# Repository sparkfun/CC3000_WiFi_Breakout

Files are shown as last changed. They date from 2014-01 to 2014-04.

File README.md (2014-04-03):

CC3000_WiFi_Breakout
====================

[TI CC3000 WiFi Breakout Board  
*CC3000 WiFi Breakout Board (WRL-12072)*](https://www.sparkfun.com/products/12072)

WiFi breakout board for the [TI CC3000 module](http://www.ti.com/product/cc3000). The datasheet can be found [here](http://www.ti.com/lit/ds/symlink/cc3000.pdf).

Arduino library and examples can be found in the [SFE_CC3000_Library](https://github.com/sparkfun/SFE_CC3000_Library).

This part was created in Eagle v6.5.0. Example sketches were created in Arduino v1.0.5.

Repository Contents
-------------------

* **/Fritzing** - [Fritzing](http://fritzing.org/) part files
* **/Hardware** - All Eagle design files (.brd, .sch, .STL)
* **/Production** - Test bed files and production panel files

Version History
---------------
* **v1.0** Initial release

License Information
-------------------
The hardware is released under [Creative Commons Share-alike 3.0](http://creativecommons.org/licenses/by-sa/3.0/).  
All other code is open source so please feel free to do anything you want with it; you buy me a beer if you use this and we meet someday ([Beerware license](http://en.wikipedia.org/wiki/Beerware)).

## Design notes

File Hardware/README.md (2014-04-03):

# What Are these Files?

The .sch and .brd files hare are Eagle CAD schematic and PCB design files.

These files were created with Eagle 6.5.0, you'll need Eagle 6.5 or later to open them up. There is a free, lite, version of Eagle available from [cadsoftusa.com](cadsoftusa.com).

# License

This product is open source! These Eagle files are released under the Creative Commons Share-Alike Attribution license ([CC BY-SA 3.0](http://creativecommons.org/licenses/by-sa/3.0/us/)).

Please use, reuse, and modify these files as you see fit. Please maintain attribution and release anything derivative under the same license.

- Your friends at SparkFun.

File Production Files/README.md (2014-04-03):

These are the production files SparkFun uses for printing PCBs, as well as the Eagle files for our test beds.

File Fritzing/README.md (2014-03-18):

* Fritzing diagram showing the CC3000 WiFi Breakout Board connected to an [Arduino Uno](https://www.sparkfun.com/products/11021)
* The subfolder contains the source files for Fritzing diagrams for the CC3000 Breakout Board.

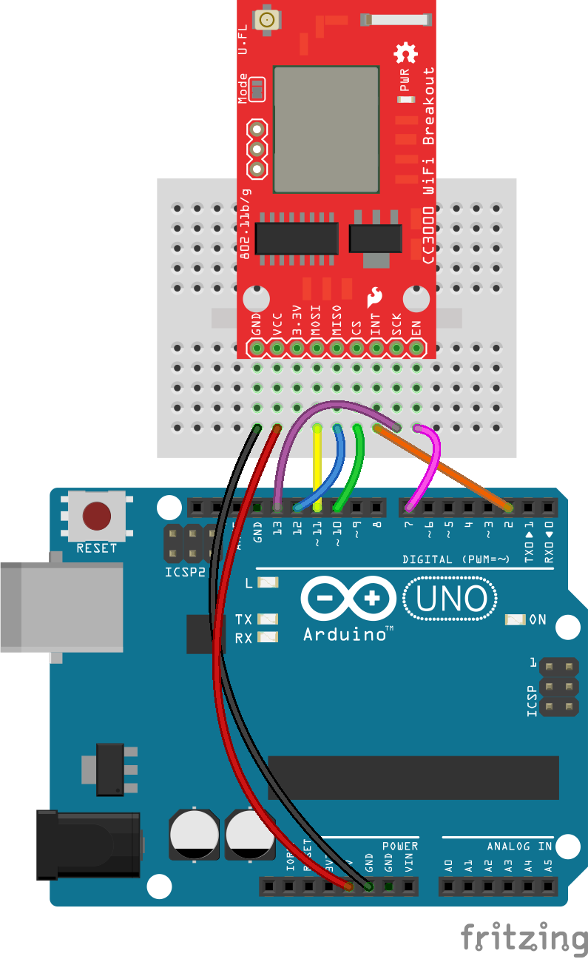
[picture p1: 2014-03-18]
Fritzing/CC3000_Breakout_Arduino_Example.png

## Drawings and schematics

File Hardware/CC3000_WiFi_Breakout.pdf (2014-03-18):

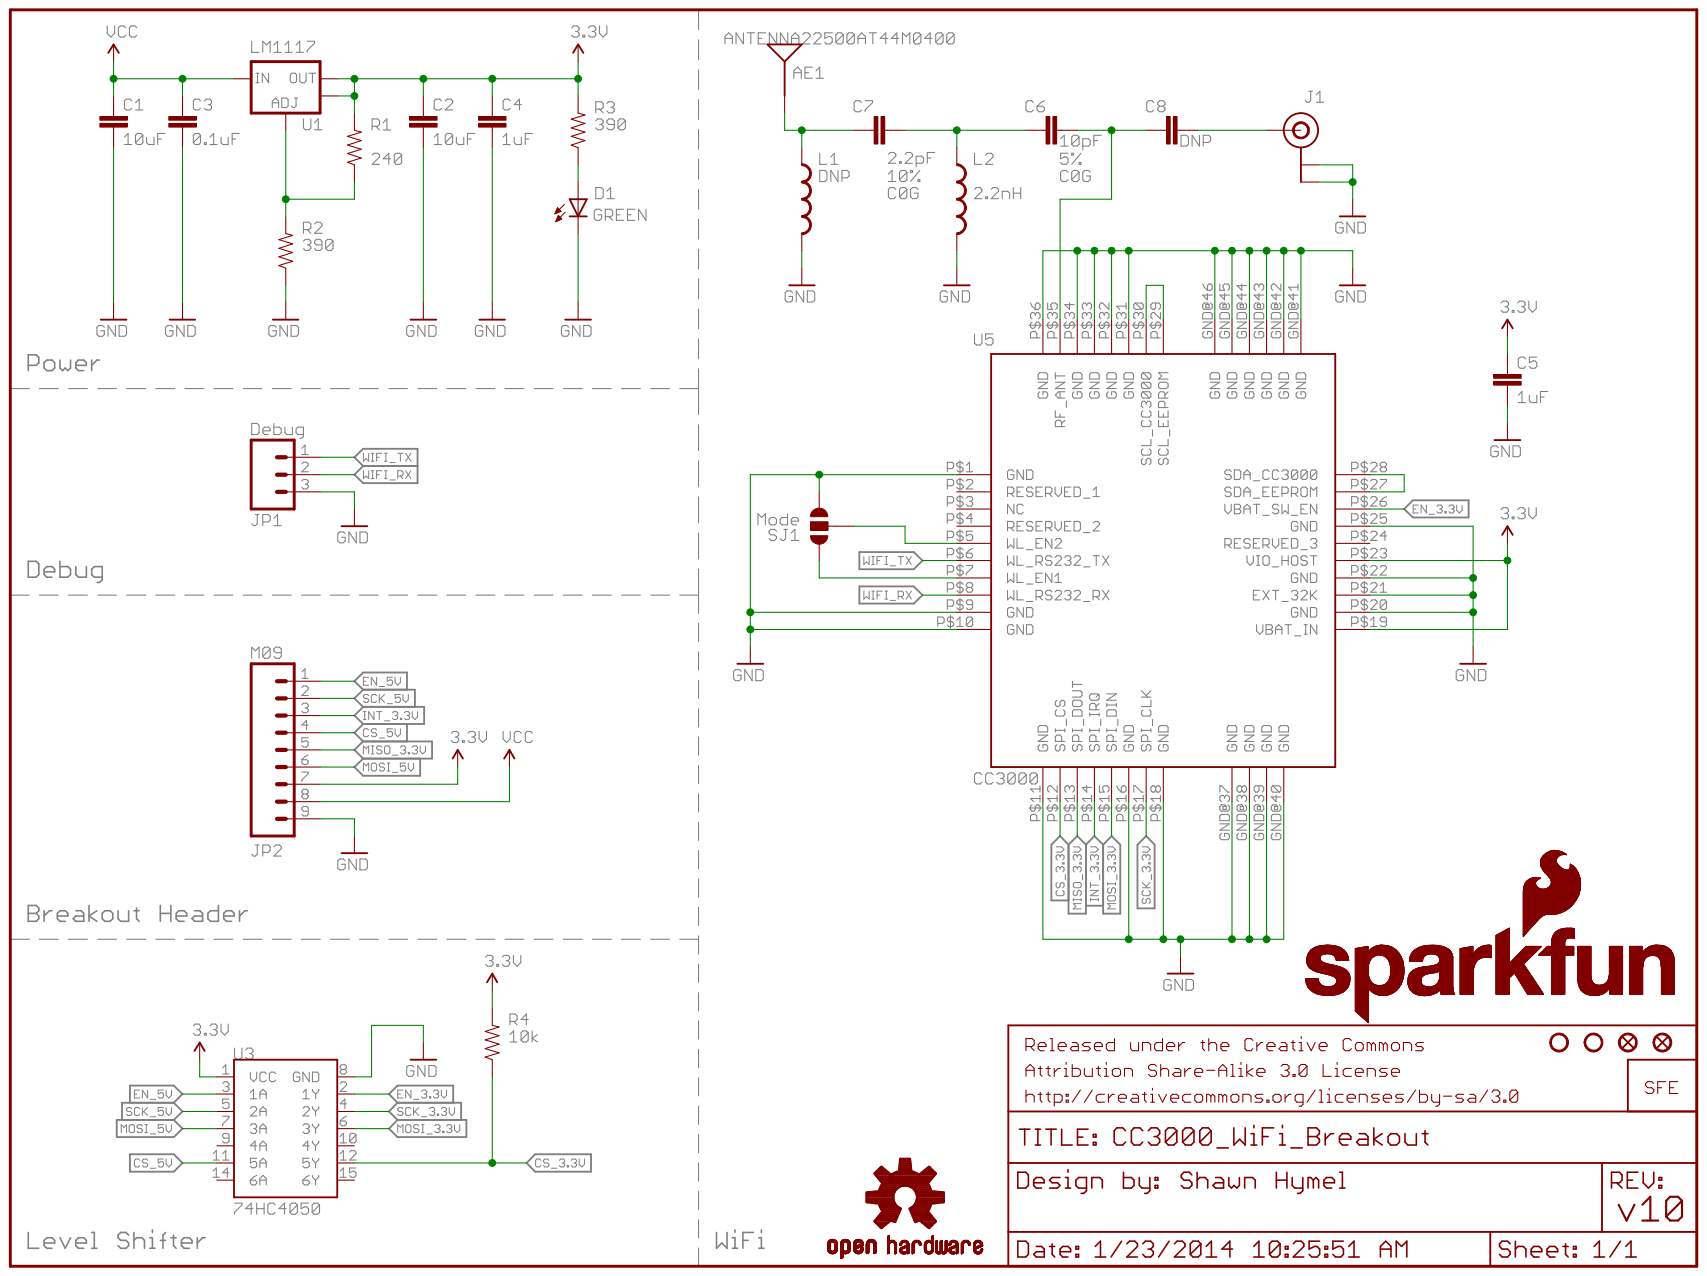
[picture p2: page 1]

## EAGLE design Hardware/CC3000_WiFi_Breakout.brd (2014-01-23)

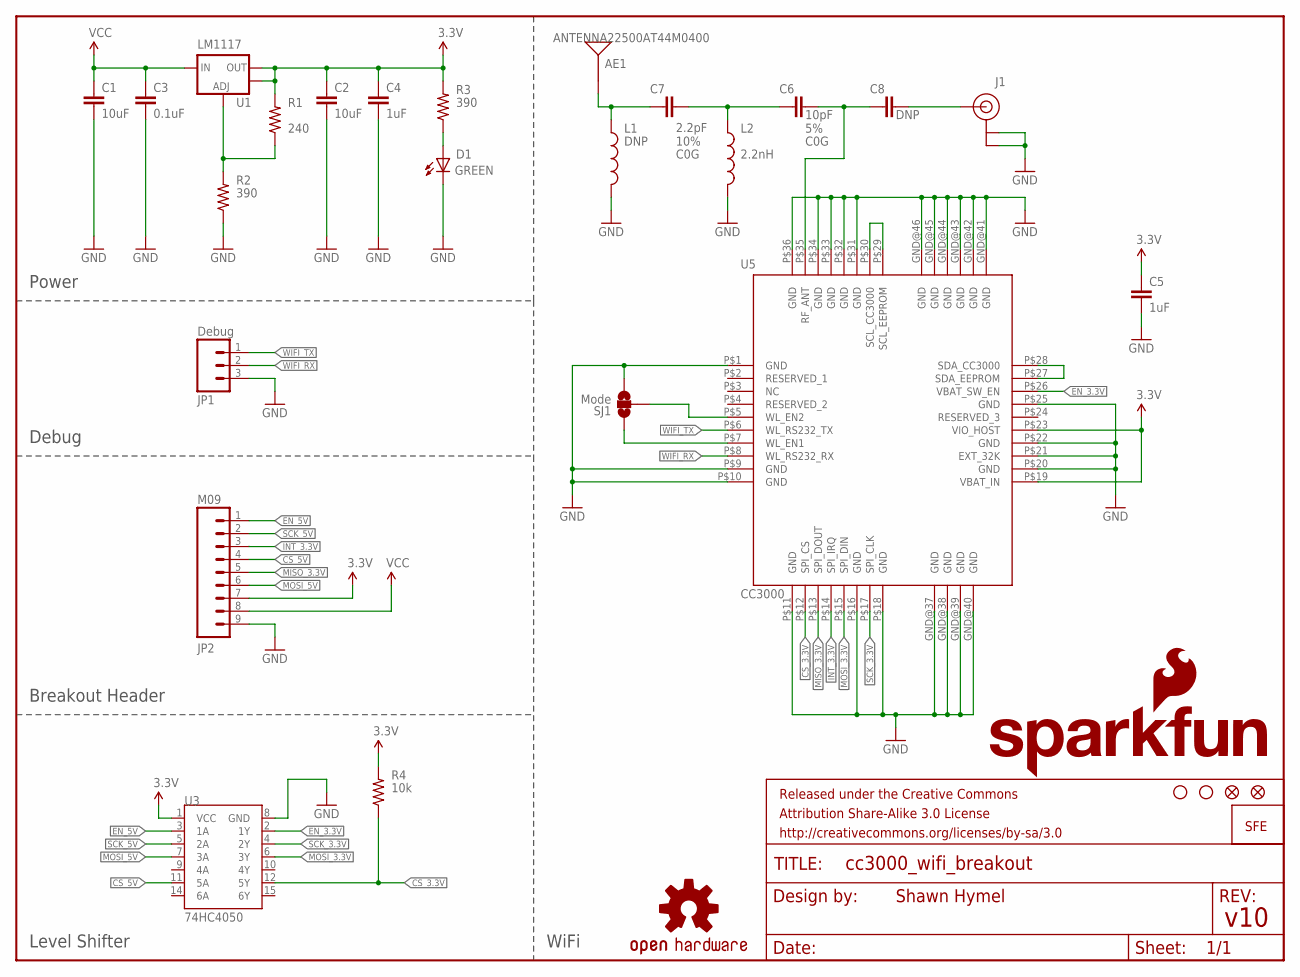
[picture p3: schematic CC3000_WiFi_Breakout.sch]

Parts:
AE1: ANTENNA22500AT44M0400; ANTENNA-CHIP_2500AT44M0400
C1, C2: 10uF; 0805
C3: 0.1uF; 0603-CAP
C4, C5: 1uF; 0805
C6: 10pF; 0603-CAP
C7: 2.2pF; 0603-CAP
C8: DNP; 0603-CAP
D1: GREEN; LED-0603
FID1, FID2: FIDUCIAL1X2; FIDUCIAL-1X2
FRAME1: FRAME-LETTER; CREATIVE_COMMONS
J1: U.FL
JP1: Debug; 1X03
JP2: M09; 1X09
L1: DNP; 0603
L2: 2.2nH; 0603
LOGO1: OSHW-LOGOS; OSHW-LOGO-S
LOGO3: LOGO-SFESK; SFE-LOGO-FLAME
LOGO4: SFE_LOGO_NAME_FLAME.1_INCH; SFE_LOGO_NAME_FLAME_.1
R1: 240; 0603-RES
R2, R3: 390; 0603-RES
R4: 10k; 0603-RES
SJ1: Mode; SJ_3_PASTE1&2
STANDOFF1, STANDOFF2: STAND-OFF
U1: LM1117; SOT223
U3: 74HC4050; SO016
U5: CC3000; QFN-46_CC3000

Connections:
3.3V: C2.1, C4.1, C5.1, JP2.7, R1.2, R3.2, R4.2, U1.2 (OUT), U1.4 (OUT), U3.1 (VCC), U5.P$19 (VBAT_IN), U5.P$23 (VIO_HOST)
CS_3.3V: R4.1, U3.12 (5Y), U5.P$12 (SPI_CS)
CS_5V: JP2.4, U3.11 (5A)
EN_3.3V: U3.2 (1Y), U5.P$26 (VBAT_SW_EN)
EN_5V: JP2.1, U3.3 (1A)
GND: C1.2, C2.2, C3.2, C4.2, C5.2, D1.C, J1.P$1 (GND), J1.P$2 (GND), JP1.3, JP2.9, L1.2, L2.2, R2.1, SJ1.3, U3.8 (GND), U5.GND@37 (GND), U5.GND@38 (GND), U5.GND@39 (GND), U5.GND@40 (GND), U5.GND@41 (GND), U5.GND@42 (GND), U5.GND@43 (GND), U5.GND@44 (GND), U5.GND@45 (GND), U5.GND@46 (GND), U5.P$1 (GND), U5.P$9 (GND), U5.P$10 (GND), U5.P$11 (GND), U5.P$16 (GND), U5.P$18 (GND), U5.P$20 (GND), U5.P$21 (EXT_32K), U5.P$22 (GND), U5.P$25 (GND), U5.P$31 (GND), U5.P$32 (GND), U5.P$33 (GND), U5.P$34 (GND), U5.P$36 (GND)
INT_3.3V: JP2.3, U5.P$14 (SPI_IRQ)
MISO_3.3V: JP2.5, U5.P$13 (SPI_DOUT)
MOSI_3.3V: U3.6 (3Y), U5.P$15 (SPI_DIN)
MOSI_5V: JP2.6, U3.7 (3A)
unnamed: R1.1, R2.2, U1.1 (ADJ)
unnamed: SJ1.2, U5.P$5 (WL_EN2)
unnamed: SJ1.1, U5.P$7 (WL_EN1)
unnamed: C6.1, C7.2, L2.1
unnamed: U5.P$27 (SDA_EEPROM), U5.P$28 (SDA_CC3000)
unnamed: U5.P$29 (SCL_EEPROM), U5.P$30 (SCL_CC3000)
unnamed: C6.2, C8.1, U5.P$35 (RF_ANT)
unnamed: C8.2, J1.P$3 (SIGNAL)
unnamed: AE1.FEED, C7.1, L1.1
unnamed: D1.A, R3.1
SCK_3.3V: U3.4 (2Y), U5.P$17 (SPI_CLK)
SCK_5V: JP2.2, U3.5 (2A)
VCC: C1.1, C3.1, JP2.8, U1.3 (IN)
WIFI_RX: JP1.2, U5.P$8 (WL_RS232_RX)
WIFI_TX: JP1.1, U5.P$6 (WL_RS232_TX)

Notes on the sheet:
Shawn Hymel
v10
Power
Debug
Breakout Header
Level Shifter
WiFi

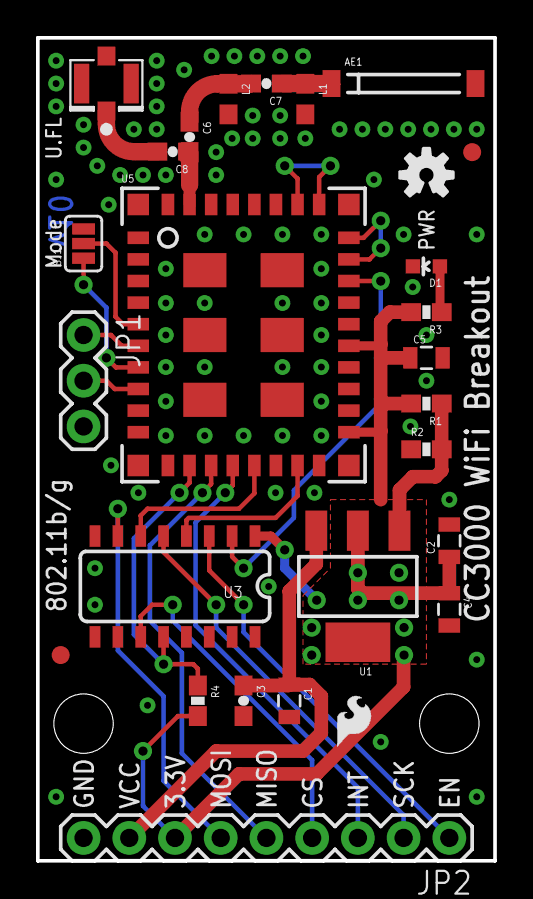
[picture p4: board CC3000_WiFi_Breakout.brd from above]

Board: 2 copper layers, 25.4 x 45.7 mm, 31 parts (1 on the bottom side), 25 nets.

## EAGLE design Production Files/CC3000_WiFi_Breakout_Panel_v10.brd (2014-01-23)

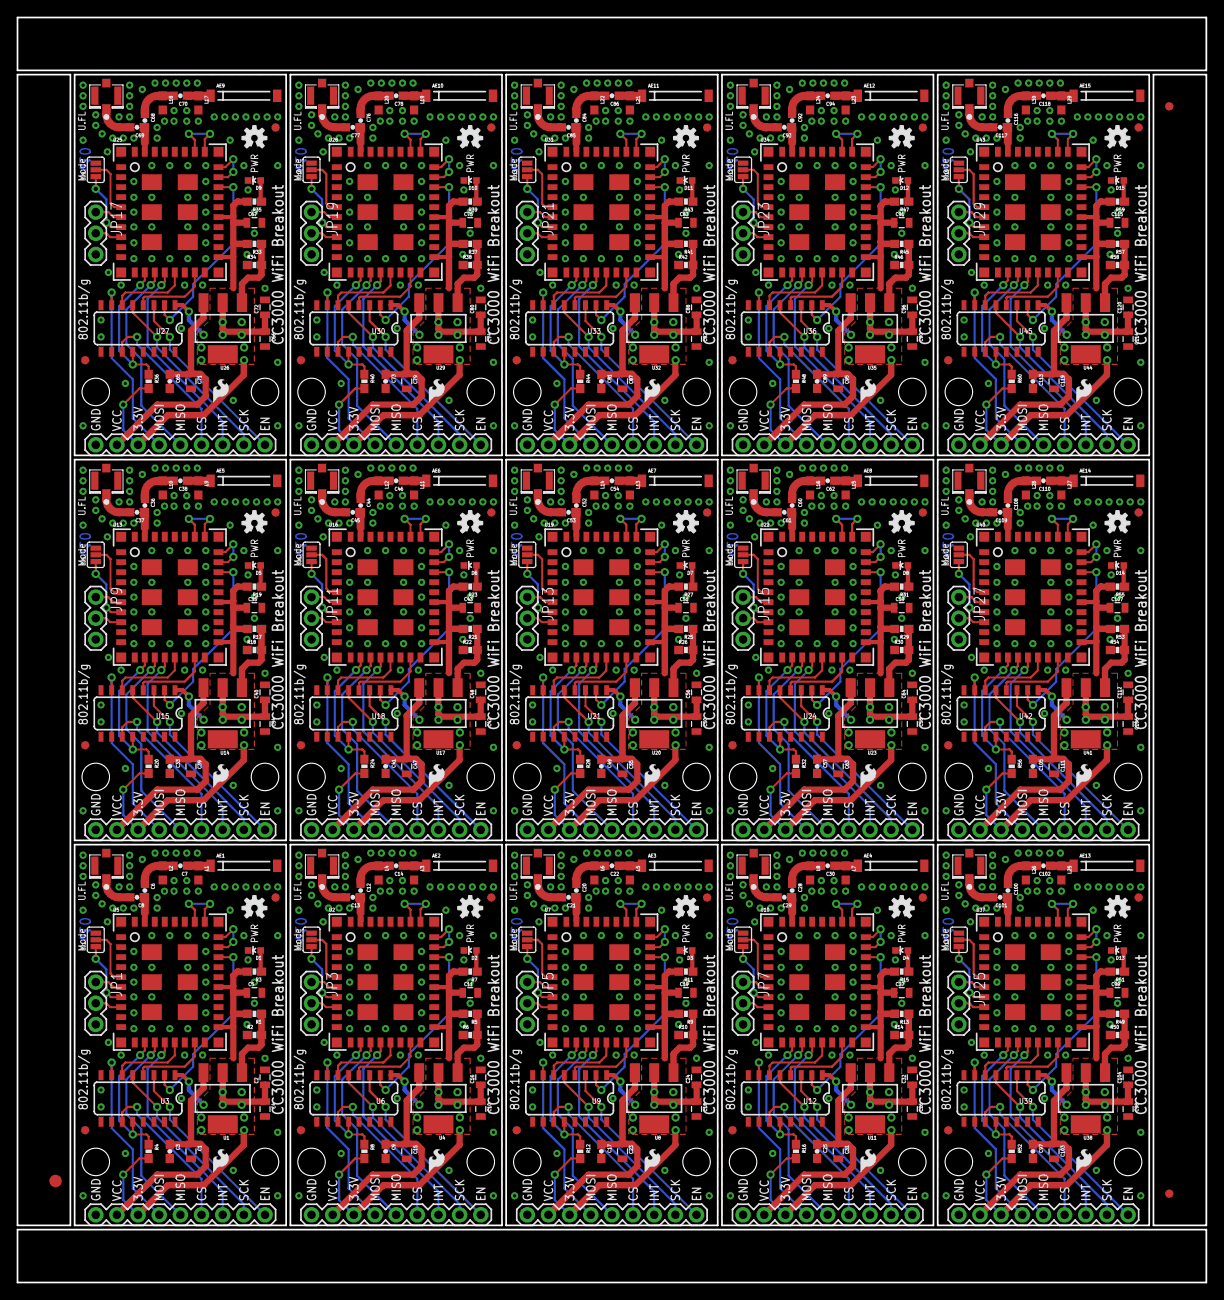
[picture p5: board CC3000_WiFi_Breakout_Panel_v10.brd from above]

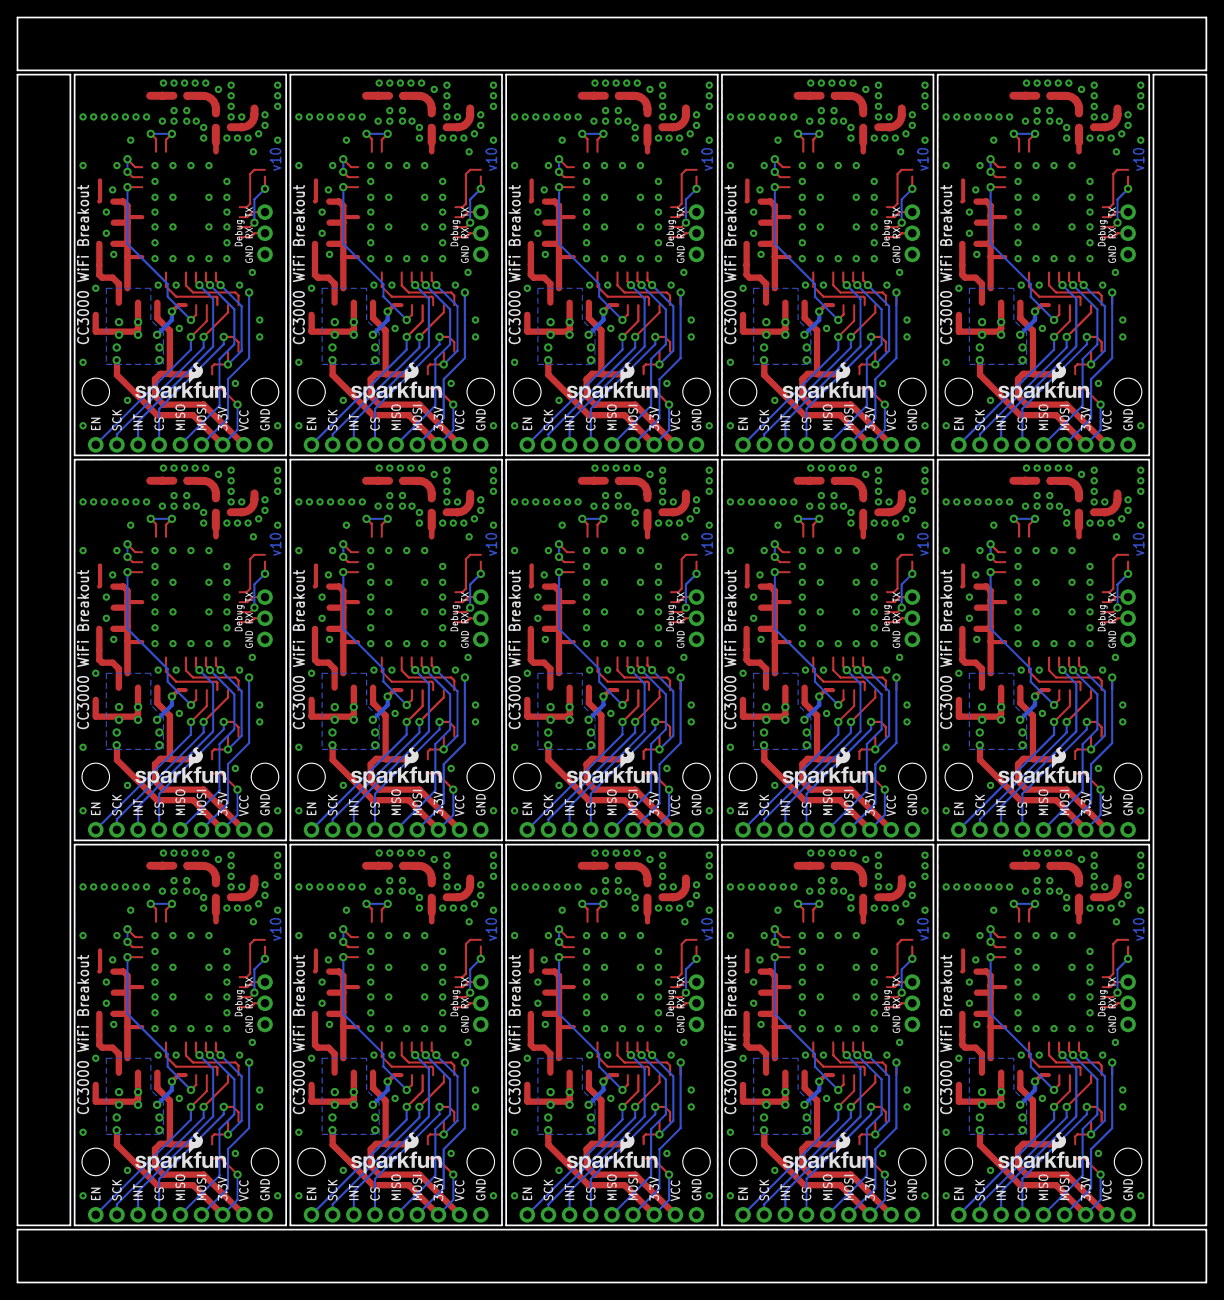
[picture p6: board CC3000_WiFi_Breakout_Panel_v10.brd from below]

Board: 2 copper layers, 142.7 x 151.9 mm, 453 parts (15 on the bottom side), 375 nets.

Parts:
AE1, AE2, AE3, AE4, AE5, AE6, AE7, AE8, AE9, AE10, AE11, AE12, AE13, AE14, AE15: ANTENNA22500AT44M0400; ANTENNA-CHIP_2500AT44M0400
C1, C2, C15, C16, C23, C24, C31, C32, C39, C40, C47, C48, C55, C56, C63, C64, C71, C72, C79, C80, C87, C88, C95, C96, C103, C104, C111, C112, C119, C120: 10uF; 0805
C3, C9, C17, C25, C33, C41, C49, C57, C65, C73, C81, C89, C97, C105, C113: 0.1uF; 0603-CAP
C4, C5, C10, C11, C18, C19, C26, C27, C34, C35, C42, C43, C50, C51, C58, C59, C66, C67, C74, C75, C82, C83, C90, C91, C98, C99, C106, C107, C114, C115: 1uF; 0805
C6, C12, C20, C28, C36, C44, C52, C60, C68, C76, C84, C92, C100, C108, C116: 10pF; 0603-CAP
C7, C14, C22, C30, C38, C46, C54, C62, C70, C78, C86, C94, C102, C110, C118: 2.2pF; 0603-CAP
C8, C13, C21, C29, C37, C45, C53, C61, C69, C77, C85, C93, C101, C109, C117: DNP; 0603-CAP
D1, D2, D3, D4, D5, D6, D7, D8, D9, D10, D11, D12, D13, D14, D15: GREEN; LED-0603
E$1: FIDUCIAL-1.5X3
E$4, E$6: FIDUCIAL-1X2
FID1, FID2, FID3, FID4, FID5, FID6, FID7, FID8, FID9, FID10, FID11, FID12, FID13, FID14, FID15, FID16, FID17, FID18, FID19, FID20, FID21, FID22, FID23, FID24, FID25, FID26, FID27, FID28, FID29, FID30: FIDUCIAL1X2; FIDUCIAL-1X2
J1, J2, J3, J4, J5, J6, J7, J8, J9, J10, J11, J12, J13, J14, J15: U.FL
JP1, JP3, JP5, JP7, JP9, JP11, JP13, JP15, JP17, JP19, JP21, JP23, JP25, JP27, JP29: Debug; 1X03
JP2, JP4, JP6, JP8, JP10, JP12, JP14, JP16, JP18, JP20, JP22, JP24, JP26, JP28, JP30: M09; 1X09
L1, L3, L5, L7, L9, L11, L13, L15, L17, L19, L21, L23, L25, L27, L29: DNP; 0603
L2, L4, L6, L8, L10, L12, L14, L16, L18, L20, L22, L24, L26, L28, L30: 2.2nH; 0603
LOGO1, LOGO2, LOGO7, LOGO10, LOGO13, LOGO16, LOGO19, LOGO22, LOGO25, LOGO28, LOGO31, LOGO34, LOGO37, LOGO40, LOGO43: OSHW-LOGOS; OSHW-LOGO-S
LOGO3, LOGO5, LOGO8, LOGO11, LOGO14, LOGO17, LOGO20, LOGO23, LOGO26, LOGO29, LOGO32, LOGO35, LOGO38, LOGO41, LOGO44: LOGO-SFESK; SFE-LOGO-FLAME
LOGO4, LOGO6, LOGO9, LOGO12, LOGO15, LOGO18, LOGO21, LOGO24, LOGO27, LOGO30, LOGO33, LOGO36, LOGO39, LOGO42, LOGO45: SFE_LOGO_NAME_FLAME.1_INCH; SFE_LOGO_NAME_FLAME_.1
R1, R5, R9, R13, R17, R21, R25, R29, R33, R37, R41, R45, R49, R53, R57: 240; 0603-RES
R2, R3, R6, R7, R10, R11, R14, R15, R18, R19, R22, R23, R26, R27, R30, R31, R34, R35, R38, R39, R42, R43, R46, R47, R50, R51, R54, R55, R58, R59: 390; 0603-RES
R4, R8, R12, R16, R20, R24, R28, R32, R36, R40, R44, R48, R52, R56, R60: 10k; 0603-RES
SJ1, SJ2, SJ3, SJ4, SJ5, SJ6, SJ7, SJ8, SJ9, SJ10, SJ11, SJ12, SJ13, SJ14, SJ15: Mode; SJ_3_PASTE1&2
STANDOFF1, STANDOFF2, STANDOFF3, STANDOFF4, STANDOFF5, STANDOFF6, STANDOFF7, STANDOFF8, STANDOFF9, STANDOFF10, STANDOFF11, STANDOFF12, STANDOFF13, STANDOFF14, STANDOFF15, STANDOFF16, STANDOFF17, STANDOFF18, STANDOFF19, STANDOFF20, STANDOFF21, STANDOFF22, STANDOFF23, STANDOFF24, STANDOFF25, STANDOFF26, STANDOFF27, STANDOFF28, STANDOFF29, STANDOFF30: STAND-OFF
U1, U4, U8, U11, U14, U17, U20, U23, U26, U29, U32, U35, U38, U41, U44: LM1117; SOT223
U2, U5, U7, U10, U13, U16, U19, U22, U25, U28, U31, U34, U37, U40, U43: CC3000; QFN-46_CC3000
U3, U6, U9, U12, U15, U18, U21, U24, U27, U30, U33, U36, U39, U42, U45: 74HC4050; SO016

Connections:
3.3V: C2.1, C4.1, C5.1, JP2.7, R1.2, R3.2, R4.2, U1.2, U1.4, U3.1, U5.P$19, U5.P$23
3.3V1: C10.1, C11.1, C16.1, JP4.7, R5.2, R7.2, R8.2, U2.P$19, U2.P$23, U4.2, U4.4, U6.1
3.3V2: C18.1, C19.1, C24.1, JP6.7, R9.2, R11.2, R12.2, U7.P$19, U7.P$23, U8.2, U8.4, U9.1
3.3V3: C26.1, C27.1, C32.1, JP8.7, R13.2, R15.2, R16.2, U10.P$19, U10.P$23, U11.2, U11.4, U12.1
3.3V4: C34.1, C35.1, C40.1, JP10.7, R17.2, R19.2, R20.2, U13.P$19, U13.P$23, U14.2, U14.4, U15.1
3.3V5: C42.1, C43.1, C48.1, JP12.7, R21.2, R23.2, R24.2, U16.P$19, U16.P$23, U17.2, U17.4, U18.1
3.3V6: C50.1, C51.1, C56.1, JP14.7, R25.2, R27.2, R28.2, U19.P$19, U19.P$23, U20.2, U20.4, U21.1
3.3V7: C58.1, C59.1, C64.1, JP16.7, R29.2, R31.2, R32.2, U22.P$19, U22.P$23, U23.2, U23.4, U24.1
3.3V8: C66.1, C67.1, C72.1, JP18.7, R33.2, R35.2, R36.2, U25.P$19, U25.P$23, U26.2, U26.4, U27.1
3.3V9: C74.1, C75.1, C80.1, JP20.7, R37.2, R39.2, R40.2, U28.P$19, U28.P$23, U29.2, U29.4, U30.1
3.3V10: C82.1, C83.1, C88.1, JP22.7, R41.2, R43.2, R44.2, U31.P$19, U31.P$23, U32.2, U32.4, U33.1
3.3V11: C90.1, C91.1, C96.1, JP24.7, R45.2, R47.2, R48.2, U34.P$19, U34.P$23, U35.2, U35.4, U36.1
3.3V12: C98.1, C99.1, C104.1, JP26.7, R49.2, R51.2, R52.2, U37.P$19, U37.P$23, U38.2, U38.4, U39.1
3.3V13: C106.1, C107.1, C112.1, JP28.7, R53.2, R55.2, R56.2, U40.P$19, U40.P$23, U41.2, U41.4, U42.1
3.3V14: C114.1, C115.1, C120.1, JP30.7, R57.2, R59.2, R60.2, U43.P$19, U43.P$23, U44.2, U44.4, U45.1
CS_3.3V: R4.1, U3.12, U5.P$12
CS_3.3V1: R8.1, U2.P$12, U6.12
CS_3.3V2: R12.1, U7.P$12, U9.12
CS_3.3V3: R16.1, U10.P$12, U12.12
CS_3.3V4: R20.1, U13.P$12, U15.12
CS_3.3V5: R24.1, U16.P$12, U18.12
CS_3.3V6: R28.1, U19.P$12, U21.12
CS_3.3V7: R32.1, U22.P$12, U24.12
CS_3.3V8: R36.1, U25.P$12, U27.12
CS_3.3V9: R40.1, U28.P$12, U30.12
CS_3.3V10: R44.1, U31.P$12, U33.12
CS_3.3V11: R48.1, U34.P$12, U36.12
CS_3.3V12: R52.1, U37.P$12, U39.12
CS_3.3V13: R56.1, U40.P$12, U42.12
CS_3.3V14: R60.1, U43.P$12, U45.12
CS_5V: JP2.4, U3.11
CS_5V1: JP4.4, U6.11
CS_5V2: JP6.4, U9.11
CS_5V3: JP8.4, U12.11
CS_5V4: JP10.4, U15.11
CS_5V5: JP12.4, U18.11
CS_5V6: JP14.4, U21.11
CS_5V7: JP16.4, U24.11
CS_5V8: JP18.4, U27.11
CS_5V9: JP20.4, U30.11
CS_5V10: JP22.4, U33.11
CS_5V11: JP24.4, U36.11
CS_5V12: JP26.4, U39.11
CS_5V13: JP28.4, U42.11
CS_5V14: JP30.4, U45.11
EN_3.3V: U3.2, U5.P$26
EN_3.3V1: U2.P$26, U6.2
EN_3.3V2: U7.P$26, U9.2
EN_3.3V3: U10.P$26, U12.2
EN_3.3V4: U13.P$26, U15.2
EN_3.3V5: U16.P$26, U18.2
EN_3.3V6: U19.P$26, U21.2
EN_3.3V7: U22.P$26, U24.2
EN_3.3V8: U25.P$26, U27.2
EN_3.3V9: U28.P$26, U30.2
EN_3.3V10: U31.P$26, U33.2
EN_3.3V11: U34.P$26, U36.2
EN_3.3V12: U37.P$26, U39.2
EN_3.3V13: U40.P$26, U42.2
EN_3.3V14: U43.P$26, U45.2
EN_5V: JP2.1, U3.3
EN_5V1: JP4.1, U6.3
EN_5V2: JP6.1, U9.3
EN_5V3: JP8.1, U12.3
EN_5V4: JP10.1, U15.3
EN_5V5: JP12.1, U18.3
EN_5V6: JP14.1, U21.3
EN_5V7: JP16.1, U24.3
EN_5V8: JP18.1, U27.3
EN_5V9: JP20.1, U30.3
EN_5V10: JP22.1, U33.3
EN_5V11: JP24.1, U36.3
EN_5V12: JP26.1, U39.3
EN_5V13: JP28.1, U42.3
EN_5V14: JP30.1, U45.3
GND: C1.2, C2.2, C3.2, C4.2, C5.2, D1.C, J1.P$1, J1.P$2, JP1.3, JP2.9, L1.2, L2.2, R2.1, SJ1.3, U3.8, U5.GND@37, U5.GND@38, U5.GND@39, U5.GND@40, U5.GND@41, U5.GND@42, U5.GND@43, U5.GND@44, U5.GND@45, U5.GND@46, U5.P$1, U5.P$9, U5.P$10, U5.P$11, U5.P$16, U5.P$18, U5.P$20, U5.P$21, U5.P$22, U5.P$25, U5.P$31, U5.P$32, U5.P$33, U5.P$34, U5.P$36
GND1: C9.2, C10.2, C11.2, C15.2, C16.2, D2.C, J2.P$1, J2.P$2, JP3.3, JP4.9, L3.2, L4.2, R6.1, SJ2.3, U2.GND@37, U2.GND@38, U2.GND@39, U2.GND@40, U2.GND@41, U2.GND@42, U2.GND@43, U2.GND@44, U2.GND@45, U2.GND@46, U2.P$1, U2.P$9, U2.P$10, U2.P$11, U2.P$16, U2.P$18, U2.P$20, U2.P$21, U2.P$22, U2.P$25, U2.P$31, U2.P$32, U2.P$33, U2.P$34, U2.P$36, U6.8
GND2: C17.2, C18.2, C19.2, C23.2, C24.2, D3.C, J3.P$1, J3.P$2, JP5.3, JP6.9, L5.2, L6.2, R10.1, SJ3.3, U7.GND@37, U7.GND@38, U7.GND@39, U7.GND@40, U7.GND@41, U7.GND@42, U7.GND@43, U7.GND@44, U7.GND@45, U7.GND@46, U7.P$1, U7.P$9, U7.P$10, U7.P$11, U7.P$16, U7.P$18, U7.P$20, U7.P$21, U7.P$22, U7.P$25, U7.P$31, U7.P$32, U7.P$33, U7.P$34, U7.P$36, U9.8
GND3: C25.2, C26.2, C27.2, C31.2, C32.2, D4.C, J4.P$1, J4.P$2, JP7.3, JP8.9, L7.2, L8.2, R14.1, SJ4.3, U10.GND@37, U10.GND@38, U10.GND@39, U10.GND@40, U10.GND@41, U10.GND@42, U10.GND@43, U10.GND@44, U10.GND@45, U10.GND@46, U10.P$1, U10.P$9, U10.P$10, U10.P$11, U10.P$16, U10.P$18, U10.P$20, U10.P$21, U10.P$22, U10.P$25, U10.P$31, U10.P$32, U10.P$33, U10.P$34, U10.P$36, U12.8
GND4: C33.2, C34.2, C35.2, C39.2, C40.2, D5.C, J5.P$1, J5.P$2, JP9.3, JP10.9, L9.2, L10.2, R18.1, SJ5.3, U13.GND@37, U13.GND@38, U13.GND@39, U13.GND@40, U13.GND@41, U13.GND@42, U13.GND@43, U13.GND@44, U13.GND@45, U13.GND@46, U13.P$1, U13.P$9, U13.P$10, U13.P$11, U13.P$16, U13.P$18, U13.P$20, U13.P$21, U13.P$22, U13.P$25, U13.P$31, U13.P$32, U13.P$33, U13.P$34, U13.P$36, U15.8
GND5: C41.2, C42.2, C43.2, C47.2, C48.2, D6.C, J6.P$1, J6.P$2, JP11.3, JP12.9, L11.2, L12.2, R22.1, SJ6.3, U16.GND@37, U16.GND@38, U16.GND@39, U16.GND@40, U16.GND@41, U16.GND@42, U16.GND@43, U16.GND@44, U16.GND@45, U16.GND@46, U16.P$1, U16.P$9, U16.P$10, U16.P$11, U16.P$16, U16.P$18, U16.P$20, U16.P$21, U16.P$22, U16.P$25, U16.P$31, U16.P$32, U16.P$33, U16.P$34, U16.P$36, U18.8
GND6: C49.2, C50.2, C51.2, C55.2, C56.2, D7.C, J7.P$1, J7.P$2, JP13.3, JP14.9, L13.2, L14.2, R26.1, SJ7.3, U19.GND@37, U19.GND@38, U19.GND@39, U19.GND@40, U19.GND@41, U19.GND@42, U19.GND@43, U19.GND@44, U19.GND@45, U19.GND@46, U19.P$1, U19.P$9, U19.P$10, U19.P$11, U19.P$16, U19.P$18, U19.P$20, U19.P$21, U19.P$22, U19.P$25, U19.P$31, U19.P$32, U19.P$33, U19.P$34, U19.P$36, U21.8
GND7: C57.2, C58.2, C59.2, C63.2, C64.2, D8.C, J8.P$1, J8.P$2, JP15.3, JP16.9, L15.2, L16.2, R30.1, SJ8.3, U22.GND@37, U22.GND@38, U22.GND@39, U22.GND@40, U22.GND@41, U22.GND@42, U22.GND@43, U22.GND@44, U22.GND@45, U22.GND@46, U22.P$1, U22.P$9, U22.P$10, U22.P$11, U22.P$16, U22.P$18, U22.P$20, U22.P$21, U22.P$22, U22.P$25, U22.P$31, U22.P$32, U22.P$33, U22.P$34, U22.P$36, U24.8
GND8: C65.2, C66.2, C67.2, C71.2, C72.2, D9.C, J9.P$1, J9.P$2, JP17.3, JP18.9, L17.2, L18.2, R34.1, SJ9.3, U25.GND@37, U25.GND@38, U25.GND@39, U25.GND@40, U25.GND@41, U25.GND@42, U25.GND@43, U25.GND@44, U25.GND@45, U25.GND@46, U25.P$1, U25.P$9, U25.P$10, U25.P$11, U25.P$16, U25.P$18, U25.P$20, U25.P$21, U25.P$22, U25.P$25, U25.P$31, U25.P$32, U25.P$33, U25.P$34, U25.P$36, U27.8
GND9: C73.2, C74.2, C75.2, C79.2, C80.2, D10.C, J10.P$1, J10.P$2, JP19.3, JP20.9, L19.2, L20.2, R38.1, SJ10.3, U28.GND@37, U28.GND@38, U28.GND@39, U28.GND@40, U28.GND@41, U28.GND@42, U28.GND@43, U28.GND@44, U28.GND@45, U28.GND@46, U28.P$1, U28.P$9, U28.P$10, U28.P$11, U28.P$16, U28.P$18, U28.P$20, U28.P$21, U28.P$22, U28.P$25, U28.P$31, U28.P$32, U28.P$33, U28.P$34, U28.P$36, U30.8
GND10: C81.2, C82.2, C83.2, C87.2, C88.2, D11.C, J11.P$1, J11.P$2, JP21.3, JP22.9, L21.2, L22.2, R42.1, SJ11.3, U31.GND@37, U31.GND@38, U31.GND@39, U31.GND@40, U31.GND@41, U31.GND@42, U31.GND@43, U31.GND@44, U31.GND@45, U31.GND@46, U31.P$1, U31.P$9, U31.P$10, U31.P$11, U31.P$16, U31.P$18, U31.P$20, U31.P$21, U31.P$22, U31.P$25, U31.P$31, U31.P$32, U31.P$33, U31.P$34, U31.P$36, U33.8
GND11: C89.2, C90.2, C91.2, C95.2, C96.2, D12.C, J12.P$1, J12.P$2, JP23.3, JP24.9, L23.2, L24.2, R46.1, SJ12.3, U34.GND@37, U34.GND@38, U34.GND@39, U34.GND@40, U34.GND@41, U34.GND@42, U34.GND@43, U34.GND@44, U34.GND@45, U34.GND@46, U34.P$1, U34.P$9, U34.P$10, U34.P$11, U34.P$16, U34.P$18, U34.P$20, U34.P$21, U34.P$22, U34.P$25, U34.P$31, U34.P$32, U34.P$33, U34.P$34, U34.P$36, U36.8
GND12: C97.2, C98.2, C99.2, C103.2, C104.2, D13.C, J13.P$1, J13.P$2, JP25.3, JP26.9, L25.2, L26.2, R50.1, SJ13.3, U37.GND@37, U37.GND@38, U37.GND@39, U37.GND@40, U37.GND@41, U37.GND@42, U37.GND@43, U37.GND@44, U37.GND@45, U37.GND@46, U37.P$1, U37.P$9, U37.P$10, U37.P$11, U37.P$16, U37.P$18, U37.P$20, U37.P$21, U37.P$22, U37.P$25, U37.P$31, U37.P$32, U37.P$33, U37.P$34, U37.P$36, U39.8
GND13: C105.2, C106.2, C107.2, C111.2, C112.2, D14.C, J14.P$1, J14.P$2, JP27.3, JP28.9, L27.2, L28.2, R54.1, SJ14.3, U40.GND@37, U40.GND@38, U40.GND@39, U40.GND@40, U40.GND@41, U40.GND@42, U40.GND@43, U40.GND@44, U40.GND@45, U40.GND@46, U40.P$1, U40.P$9, U40.P$10, U40.P$11, U40.P$16, U40.P$18, U40.P$20, U40.P$21, U40.P$22, U40.P$25, U40.P$31, U40.P$32, U40.P$33, U40.P$34, U40.P$36, U42.8
GND14: C113.2, C114.2, C115.2, C119.2, C120.2, D15.C, J15.P$1, J15.P$2, JP29.3, JP30.9, L29.2, L30.2, R58.1, SJ15.3, U43.GND@37, U43.GND@38, U43.GND@39, U43.GND@40, U43.GND@41, U43.GND@42, U43.GND@43, U43.GND@44, U43.GND@45, U43.GND@46, U43.P$1, U43.P$9, U43.P$10, U43.P$11, U43.P$16, U43.P$18, U43.P$20, U43.P$21, U43.P$22, U43.P$25, U43.P$31, U43.P$32, U43.P$33, U43.P$34, U43.P$36, U45.8
INT_3.3V: JP2.3, U5.P$14
INT_3.3V1: JP4.3, U2.P$14
INT_3.3V2: JP6.3, U7.P$14
INT_3.3V3: JP8.3, U10.P$14
INT_3.3V4: JP10.3, U13.P$14
INT_3.3V5: JP12.3, U16.P$14
INT_3.3V6: JP14.3, U19.P$14
INT_3.3V7: JP16.3, U22.P$14
INT_3.3V8: JP18.3, U25.P$14
INT_3.3V9: JP20.3, U28.P$14
INT_3.3V10: JP22.3, U31.P$14
INT_3.3V11: JP24.3, U34.P$14
INT_3.3V12: JP26.3, U37.P$14
INT_3.3V13: JP28.3, U40.P$14
INT_3.3V14: JP30.3, U43.P$14
MISO_3.3V: JP2.5, U5.P$13
MISO_3.3V1: JP4.5, U2.P$13
MISO_3.3V2: JP6.5, U7.P$13
MISO_3.3V3: JP8.5, U10.P$13
MISO_3.3V4: JP10.5, U13.P$13
MISO_3.3V5: JP12.5, U16.P$13
MISO_3.3V6: JP14.5, U19.P$13
MISO_3.3V7: JP16.5, U22.P$13
MISO_3.3V8: JP18.5, U25.P$13
MISO_3.3V9: JP20.5, U28.P$13
MISO_3.3V10: JP22.5, U31.P$13
MISO_3.3V11: JP24.5, U34.P$13
MISO_3.3V12: JP26.5, U37.P$13
MISO_3.3V13: JP28.5, U40.P$13
MISO_3.3V14: JP30.5, U43.P$13
MOSI_3.3V: U3.6, U5.P$15
MOSI_3.3V1: U2.P$15, U6.6
MOSI_3.3V2: U7.P$15, U9.6
MOSI_3.3V3: U10.P$15, U12.6
MOSI_3.3V4: U13.P$15, U15.6
MOSI_3.3V5: U16.P$15, U18.6
MOSI_3.3V6: U19.P$15, U21.6
MOSI_3.3V7: U22.P$15, U24.6
MOSI_3.3V8: U25.P$15, U27.6
MOSI_3.3V9: U28.P$15, U30.6
MOSI_3.3V10: U31.P$15, U33.6
MOSI_3.3V11: U34.P$15, U36.6
MOSI_3.3V12: U37.P$15, U39.6
MOSI_3.3V13: U40.P$15, U42.6
MOSI_3.3V14: U43.P$15, U45.6
MOSI_5V: JP2.6, U3.7
MOSI_5V1: JP4.6, U6.7
MOSI_5V2: JP6.6, U9.7
MOSI_5V3: JP8.6, U12.7
MOSI_5V4: JP10.6, U15.7
MOSI_5V5: JP12.6, U18.7
MOSI_5V6: JP14.6, U21.7
MOSI_5V7: JP16.6, U24.7
MOSI_5V8: JP18.6, U27.7
MOSI_5V9: JP20.6, U30.7
MOSI_5V10: JP22.6, U33.7
MOSI_5V11: JP24.6, U36.7
MOSI_5V12: JP26.6, U39.7
MOSI_5V13: JP28.6, U42.7
MOSI_5V14: JP30.6, U45.7
unnamed: R1.1, R2.2, U1.1
unnamed: SJ1.2, U5.P$5
unnamed: SJ1.1, U5.P$7
unnamed: C6.1, C7.2, L2.1
unnamed: U5.P$27, U5.P$28
unnamed: U5.P$29, U5.P$30
unnamed: C6.2, C8.1, U5.P$35
unnamed: C8.2, J1.P$3
unnamed: AE1.FEED, C7.1, L1.1
unnamed: D1.A, R3.1
unnamed: R5.1, R6.2, U4.1
unnamed: SJ2.2, U2.P$5
unnamed: SJ2.1, U2.P$7
unnamed: U2.P$27, U2.P$28
unnamed: U2.P$29, U2.P$30
unnamed: C12.1, C14.2, L4.1
unnamed: AE2.FEED, C14.1, L3.1
unnamed: C13.2, J2.P$3
unnamed: D2.A, R7.1
unnamed: C12.2, C13.1, U2.P$35
unnamed: R9.1, R10.2, U8.1
unnamed: SJ3.2, U7.P$5
unnamed: SJ3.1, U7.P$7
unnamed: U7.P$27, U7.P$28
unnamed: U7.P$29, U7.P$30
unnamed: C20.1, C22.2, L6.1
unnamed: AE3.FEED, C22.1, L5.1
unnamed: C21.2, J3.P$3
unnamed: D3.A, R11.1
unnamed: C20.2, C21.1, U7.P$35
unnamed: R13.1, R14.2, U11.1
unnamed: SJ4.2, U10.P$5
unnamed: SJ4.1, U10.P$7
unnamed: U10.P$27, U10.P$28
unnamed: U10.P$29, U10.P$30
unnamed: C28.1, C30.2, L8.1
unnamed: AE4.FEED, C30.1, L7.1
unnamed: C29.2, J4.P$3
unnamed: D4.A, R15.1
unnamed: C28.2, C29.1, U10.P$35
unnamed: R17.1, R18.2, U14.1
unnamed: SJ5.2, U13.P$5
unnamed: SJ5.1, U13.P$7
unnamed: U13.P$27, U13.P$28
unnamed: U13.P$29, U13.P$30
unnamed: C36.1, C38.2, L10.1
unnamed: AE5.FEED, C38.1, L9.1
unnamed: C37.2, J5.P$3
unnamed: D5.A, R19.1
unnamed: C36.2, C37.1, U13.P$35
unnamed: R21.1, R22.2, U17.1
unnamed: SJ6.2, U16.P$5
unnamed: SJ6.1, U16.P$7
unnamed: U16.P$27, U16.P$28
unnamed: U16.P$29, U16.P$30
unnamed: C44.1, C46.2, L12.1
unnamed: AE6.FEED, C46.1, L11.1
unnamed: C45.2, J6.P$3
unnamed: D6.A, R23.1
unnamed: C44.2, C45.1, U16.P$35
unnamed: R25.1, R26.2, U20.1
unnamed: SJ7.2, U19.P$5
unnamed: SJ7.1, U19.P$7
unnamed: U19.P$27, U19.P$28
unnamed: U19.P$29, U19.P$30
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

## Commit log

2013-09-18 Created schematic and initial layout
    [CC3000_WiFi_Breakout.brd, CC3000_WiFi_Breakout.sch]
2013-09-19 Layout (mostly) done
    [CC3000_WiFi_Breakout.brd, CC3000_WiFi_Breakout.sch]
2013-09-19 Proto layout complete. Needs aesthetics.
    [CC3000_WiFi_Breakout.brd, CC3000_WiFi_Breakout.sch]
2013-09-20 Prototype board ready for review
    [CC3000_WiFi_Breakout.brd, CC3000_WiFi_Breakout.sch]
2013-09-23 Ready for prototype
    [CC3000_WiFi_Breakout.brd, CC3000_WiFi_Breakout.sch]
2013-12-12 Changed layout for board
    [CC3000_WiFi_Breakout.brd, CC3000_WiFi_Breakout.sch]
2013-12-13 Redid layout. Again.
    [CC3000_WiFi_Breakout.brd, CC3000_WiFi_Breakout.sch]
2013-12-16 Moved headers closer to board edge
    [CC3000_WiFi_Breakout.brd]
2014-01-16 Moved SS Flame down, added pin marker for U.FL in SS
    [CC3000_WiFi_Breakout.brd, CC3000_WiFi_Breakout.sch]
2014-01-23 Added silk U.FL; adjusted tvalue markings for easier reading
    [CC3000_WiFi_Breakout.brd, CC3000_WiFi_Breakout.sch]
2014-01-23 Created Panel
    [CC3000_WiFi_Breakout_Panel_v10.brd]
2014-03-18 Added Fritzing parts
    [CC3000_Breakout_Arduino_Example.fzz]
2014-03-18 Added pdf of schematic

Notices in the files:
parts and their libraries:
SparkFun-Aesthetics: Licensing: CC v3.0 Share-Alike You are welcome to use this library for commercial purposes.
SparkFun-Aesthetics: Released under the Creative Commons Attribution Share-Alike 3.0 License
